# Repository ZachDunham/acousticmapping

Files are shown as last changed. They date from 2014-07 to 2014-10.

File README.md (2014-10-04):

acousticmapping
===============

Data vis, light painting mashup exploring room acoustics 

## Synopsis 
The goal for this project is to be able to photograph standing wave interference to create a kind of acoustical map of a room. Wave interference, simply put, is caused when two waves of the same frequency but different phase combine and result in a waveform that has an increased or decreased amplitude. 

In order to photograph these interference or standing wave patterns, I'm playing a range of sine tones but only working with one frequency at a time in order to isolate these interferences. In any listening situation there are direct and reflected sounds. As sound leaves the source it propagates outward, reflecting off of surfaces along the way, until it reaches your ears. Depending on where you are in the room, some portion of this sound also travels directly to the ear. Because of these alternate routes (reflected and direct) we end up with differences in arrival time which can also mean differences in the phase (angle) of the wave. As these in- or out-of-phase signals reach our ear, they can cancel each other out or combine to result in a larger waveform.

The hardware and software here are part of this ongoing project.  

## Liscense 
In the interest of collaboration and good will, the files herein are offered for public use. Just don't be a jerk about it and credit me if you use it commercially :)

## CONTAINED HEREIN
* Embedded systems design files: Namely .brd, .sch
* Firmware: Arduino sketches

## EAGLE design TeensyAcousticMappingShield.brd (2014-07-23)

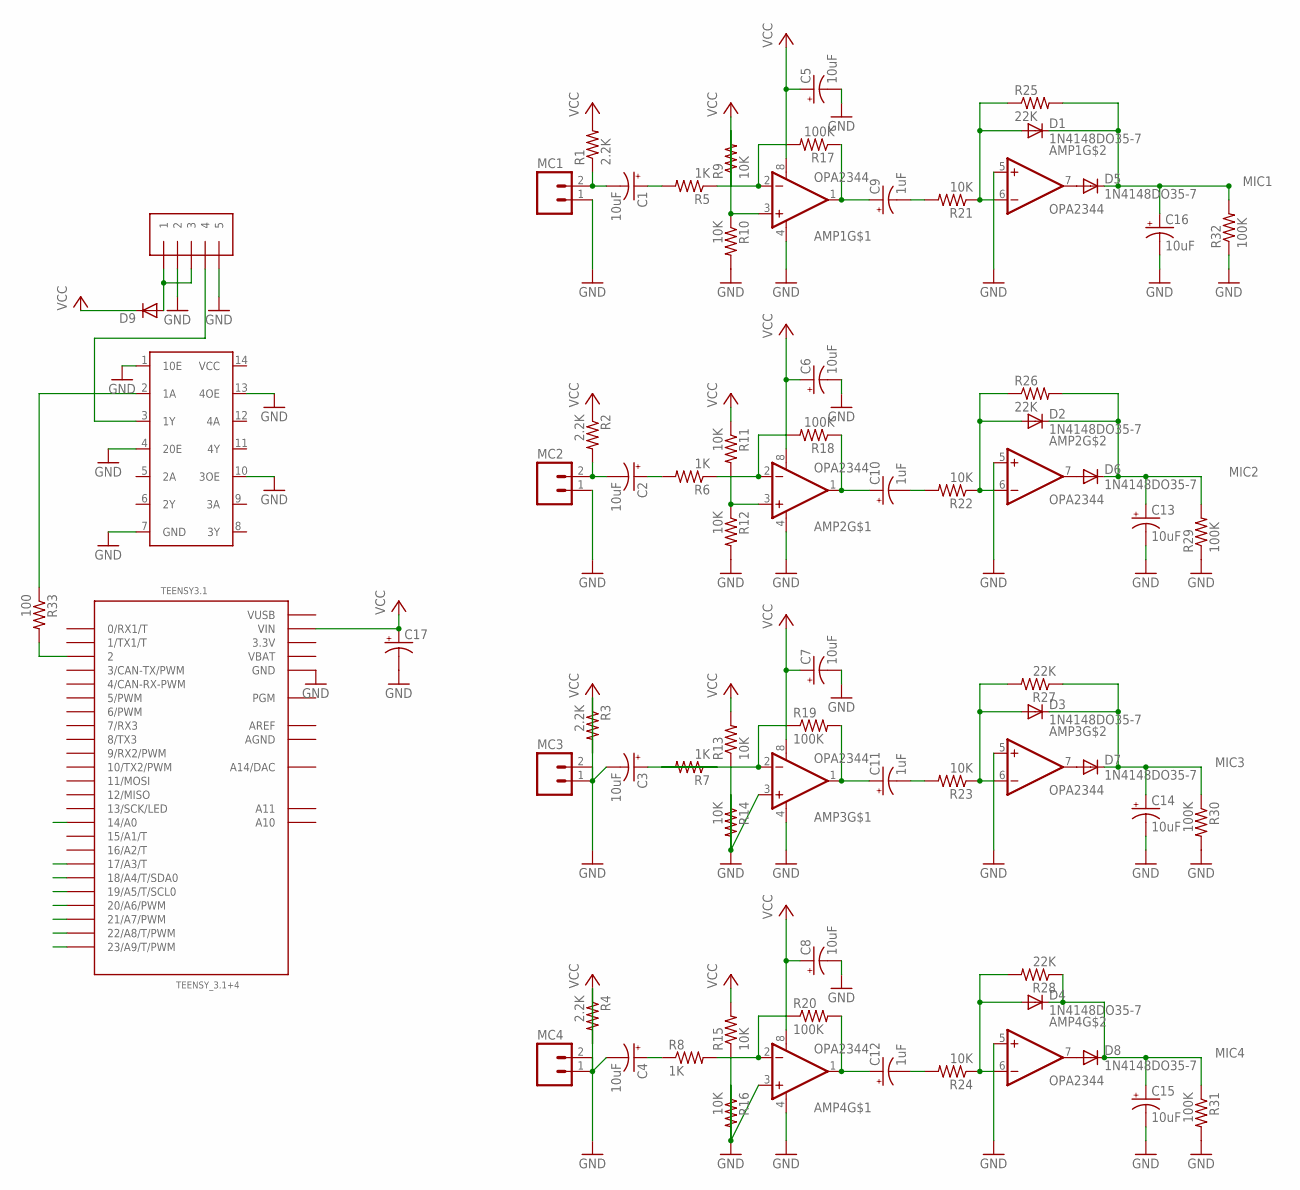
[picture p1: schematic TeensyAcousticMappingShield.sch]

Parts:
AMP1, AMP2, AMP3, AMP4: OPA2344; DIP08
C1, C2, C3, C4, C5, C6, C7, C8, C13, C14, C15, C16: 10uF; E2-4
C9, C10, C11, C12: 1uF; E2-4
C17: CPOL-USE2.5-6; E2,5-6
D1, D2, D3, D4, D5, D6, D7, D8: 1N4148DO35-7; DO35-7
D9: DIODE-C1702-05; C1702-05
IO: 1X5; 1X05-3.5MM
LEVELSHIFT: 74AHCT125; DIL14
MC1, MC2, MC3, MC4: M02LOCK_LONGPADS; 1X02_LOCK_LONGPADS
R1, R2, R3, R4: 2.2K; 0207/2V
R5, R6, R7, R8: 1K; 0207/2V
R9, R10, R11, R12, R13, R14, R15, R16, R21, R22, R23, R24: 10K; 0207/2V
R17, R18, R19, R20, R29, R30, R31, R32: 100K; 0207/2V
R25, R26, R27, R28: 22K; 0207/2V
R33: 100; 0207/2V
TEENSY3.1: TEENSY_3.1+4

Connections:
3.3V: TEENSY3.1.3.3V, TEENSY3.1.3.3V1 (3.3V)
AGND: TEENSY3.1.AGND
AREF: TEENSY3.1.AREF
B+: D9.A, IO.1, IO.3
GND: AMP1.4 (V-), AMP1.5 (+IN), AMP2.4 (V-), AMP2.5 (+IN), AMP3.4 (V-), AMP3.5 (+IN), AMP4.4 (V-), AMP4.5 (+IN), C5.-, C6.-, C7.-, C8.-, C13.-, C14.-, C15.-, C16.-, C17.-, IO.2, IO.5, LEVELSHIFT.1 (10E), LEVELSHIFT.4 (20E), LEVELSHIFT.7 (GND), LEVELSHIFT.10 (3OE), LEVELSHIFT.13 (4OE), MC1.1, MC2.1, MC3.2, MC4.2, R10.2, R12.2, R14.1, R16.1, R29.1, R32.1, TEENSY3.1.GND, TEENSY3.1.GND1 (GND)
MIC1: C16.+, D1.C, D5.C, R25.2, R32.2, TEENSY3.1.14/A0
MIC2: C13.+, D2.C, D6.C, R26.2, R29.2, TEENSY3.1.17/A3 (17/A3/T)
MIC3: C14.+, D3.C, D7.C, R27.1, R30.1, TEENSY3.1.18/A4 (18/A4/T/SDA0)
MIC4: C15.+, D4.C, D8.C, R28.1, R31.1, TEENSY3.1.19/A5 (19/A5/T/SCL0)
unnamed: AMP1.3 (+IN), R9.2, R10.1
unnamed: AMP1.2 (-IN), R5.1, R17.2
unnamed: AMP1.1 (OUT), C9.+, R17.1
unnamed: C1.+, R5.2
unnamed: C1.-, MC1.2, R1.1
unnamed: C9.-, R21.2
unnamed: AMP1.6 (-IN), D1.A, R21.1, R25.1
unnamed: AMP1.7 (OUT), D5.A
unnamed: AMP2.3 (+IN), R11.2, R12.1
unnamed: AMP2.2 (-IN), R6.1, R18.2
unnamed: AMP2.1 (OUT), C10.+, R18.1
unnamed: C2.+, R6.2
unnamed: C2.-, MC2.2, R2.2
unnamed: C10.-, R22.2
unnamed: AMP2.6 (-IN), D2.A, R22.1, R26.1
unnamed: AMP2.7 (OUT), D6.A
unnamed: AMP3.3 (+IN), R13.1, R14.2
unnamed: R33.2, TEENSY3.1.2
unnamed: LEVELSHIFT.2 (1A), R33.1
unnamed: AMP3.2 (-IN), R7.2, R19.1
unnamed: AMP3.1 (OUT), C11.+, R19.2
unnamed: C3.+, R7.1
unnamed: C3.-, MC3.1, R3.1
unnamed: C11.-, R23.2
unnamed: AMP3.6 (-IN), D3.A, R23.1, R27.2
unnamed: AMP3.7 (OUT), D7.A
unnamed: AMP4.3 (+IN), R15.1, R16.2
unnamed: AMP4.2 (-IN), R8.2, R20.1
unnamed: AMP4.1 (OUT), C12.+, R20.2
unnamed: C4.+, R8.1
unnamed: C4.-, MC4.1, R4.1
unnamed: C12.-, R24.2
unnamed: AMP4.6 (-IN), D4.A, R24.1, R28.2
unnamed: AMP4.7 (OUT), D8.A
unnamed: IO.4, LEVELSHIFT.3 (1Y)
VBAT: TEENSY3.1.VBAT
VCC: AMP1.8 (V+), AMP2.8 (V+), AMP3.8 (V+), AMP4.8 (V+), C5.+, C6.+, C7.+, C8.+, C17.+, D9.C, R1.2, R2.1, R3.2, R4.2, R9.1, R11.1, R13.2, R15.2, TEENSY3.1.VIN
VUSB: TEENSY3.1.VUSB

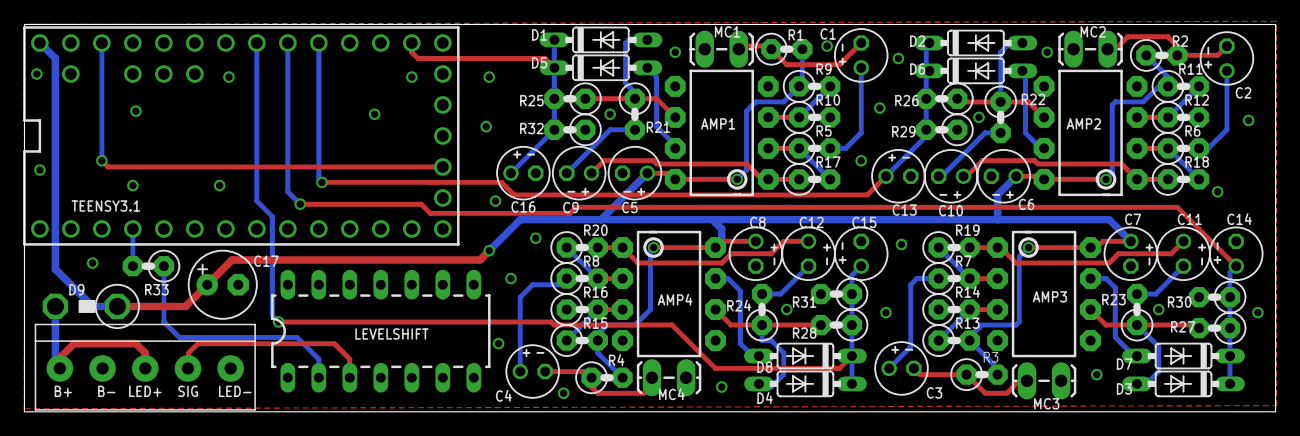
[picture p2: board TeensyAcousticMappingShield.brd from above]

Board: 2 copper layers, 102.5 x 31.8 mm, 70 parts (0 on the bottom side), 43 nets.

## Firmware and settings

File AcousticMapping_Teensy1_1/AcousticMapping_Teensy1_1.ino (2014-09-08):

#include <OctoWS2811.h>

const int ledsPerStrip = 144;

DMAMEM int displayMemory[ledsPerStrip*6];
int drawingMemory[ledsPerStrip*6];

const int config = WS2811_GRB | WS2811_800kHz;

OctoWS2811 leds(ledsPerStrip, displayMemory, drawingMemory, config);

const int num_lights = 144;
const int num_mics = 4;
const int brightness_steps = 4;

int val = 0;                     // value to store mic1
int val2 = 0;                    // value to store mic2 
int val3 = 0;                    // value to store mic 3
int val4 = 0;                    //value to store mic 4
// colors 
int r = 30;                      // red value 
int g = 0;                       // green value
int b = 30;                      // blue value

int ressteps = 1000;
const int numReadings = 20;      // number of readings for smoothing the inputs 

int readings[numReadings];       // the readings from the analog input
int total = 0;                   // the running total
int average = 0;                 // average of mic 1
int myIndex = 0;

int readings2[numReadings];      // the readings from the analog input
int total2 = 0;                  // the running total
int average2 = 0;                // average of mic 2
int myIndex2 = 0;

int readings3[numReadings];      // the readings from the analog input
int total3 = 0;                  // the running total
int average3 = 0;                // average of mic 3
int myIndex3 = 0;

int readings4[numReadings];      // the readings from the analog input
int total4 = 0;                  // the running total
int average4 = 0;                // average of mic 4
int myIndex4 = 0;

const int mic = 3;      // pin that mic1 is attached to
const int mic2 = 4;      // pin that mic2 is attached to 
const int mic3 = 5;      // pin that mic3 is attached to 
const int mic4 = 8;      // pin that mic4 is attached to 


const int ledPin = 9;           // pin that the LED is attached to
const int indicatorLedPin = 13; // pin that the built-in LED is attached to
const int buttonPin = 8;        // pin that the button is attached to


// These variables will change:
int sensorMin = 1023;  // minimum sensor value
int sensorMin2 = 1023;  // minimum sensor value2
int sensorMin3 = 1023;  // minimum sensor value3
int sensorMin4 = 1023;  // minimum sensor value4

int sensorMax = 0;     // maximum sensor value
int sensorMax2 = 0;    // maximum sensor value2
int sensorMax3 = 0;     // maximum sensor value3
int sensorMax4 = 0;     // maximum sensor value4

int sensorMaxAVG = 0;  //average max of all 4 mics 

int ledsize = (num_lights / num_mics); //size of without the * i

int x = 1.5;
/*-----------------------------------------------------------------------------------------
/////////////////////////////////////////////////////////////////////////////////////////
-----------------------------------------------------------------------------------------*/
void setup() {
  leds.begin();          // initialize pixel strip
  leds.show();           // Initialize all pixels to 'off'
  pinMode(indicatorLedPin, OUTPUT); 
  pinMode (ledPin, OUTPUT);
  pinMode (buttonPin, INPUT);
  Serial.begin(9600);

  //CALIBRATE ALL MIC'S MIN & MAX//
  
  for(int c=0; c<4000; c++){  
  calibrate_Lights(c);  
  digitalWrite(indicatorLedPin, HIGH);
    val  = running_Average(mic);     // Grab the average of Mic 1 
    val2 = running_Average2(mic2);   // Grab the average of Mic 2
    val3 = running_Average3(mic3);   // Grab the average of Mic 3
    val4 = running_Average4(mic4);   // Grab the average of Mic 4
    
    // record the maximum/minimum sensor value1
    if (val > sensorMax) {
    sensorMax = val;
    }
    if (val < sensorMin) {
    sensorMin = val;
    }
    // record the maximum/minimum sensor value2
    if (val2 > sensorMax2) {
    sensorMax2 = val2;
    }
    if (val2 < sensorMin2) {
    sensorMin2 = val2;
    }
    // record the maximum/minimum sensor value3
    if (val3 > sensorMax3) {
    sensorMax3 = val3;
    }
    if (val3 < sensorMin3) {
    sensorMin3 = val3;
    }
    // record the maximum/minimum sensor value4
    if (val4 > sensorMax4) {
    sensorMax4 = val4;
    }
    if (val4 < sensorMin4) {
    sensorMin4 = val4;
    }
  }
  sensorMaxAVG = ((sensorMin+sensorMin2+sensorMin3+sensorMin4)/4);
  digitalWrite(indicatorLedPin, LOW);

}
void loop() {
 //mic 1 
 val = running_Average(mic);  // smooth the mic readings with Running Average function
 Serial.println(val);
 val = map(val, sensorMin, sensorMaxAVG, 0, ressteps);  // map the range to res steps
 val = constrain(val, 0, ressteps);
 newledRange(val, 1); 

 //mic2
 val2 = running_Average2(mic2);  // smooth the mic readings with Running Average function
 val2 = map(val2, sensorMin2, sensorMaxAVG, 0, ressteps);  // map the range to 0-255
 val2 = constrain(val2, 0, ressteps);
 newledRange(val2, 2); 

 //mic3
 val3 = running_Average3(mic3);  // smooth the mic readings with Running Average function
 val3 = map(val3, sensorMin3, sensorMaxAVG, 0, ressteps);  // map the range to 0-255
 val3 = constrain(val3, 0, ressteps);
 newledRange(val3, 3); 

 //mic4
 val4 = running_Average4(mic4);  // smooth the mic readings with Running Average function
 val4 = map(val4, sensorMin4, sensorMaxAVG, 0, ressteps);  // map the range to 0-255
 val4 = constrain(val4, 0, ressteps);
 newledRange(val4, 4); 


leds.show();                               // refresh the strip

}

//AVERAGE MIC 1//
int running_Average(int input){  
  // subtract the last reading:
  total= total - readings[myIndex];         
  // read from the sensor:  
  readings[myIndex] = analogRead(input); 
  // add the reading to the total:
  total= total + readings[myIndex];       
  // advance to the next position in the array:  
  myIndex = myIndex + 1;                    

  // if we're at the end of the array...
  if (myIndex >= numReadings)              
    // ...wrap around to the beginning: 
    myIndex = 0;                           

  // calculate the average:
  average = total / numReadings;  
  delay(1);  
  // send it to the computer as ASCII digits
  return average;   
}
int running_Average2(int input){  
  // subtract the last reading:
  total2= total2 - readings2[myIndex2];         
  // read from the sensor:  
  readings2[myIndex2] = analogRead(input); 
  // add the reading to the total:
  total2= total2 + readings2[myIndex2];       
  // advance to the next position in the array:  
  myIndex2 = myIndex2 + 1;                    

  // if we're at the end of the array...
  if (myIndex2 >= numReadings)              
    // ...wrap around to the beginning: 
    myIndex2 = 0;                           

  // calculate the average:
  average2 = total2 / numReadings;  
  delay(1);  
  // send it to the computer as ASCII digits
  return average2;            
}
//AVERAGES MIC 3
int running_Average3(int input){  
  // subtract the last reading:
  total3= total3 - readings3[myIndex3];         
  // read from the sensor:  
  readings3[myIndex3] = analogRead(input); 
  // add the reading to the total:
  total3= total3 + readings3[myIndex3];       
  // advance to the next position in the array:  
  myIndex3 = myIndex3 + 1;                    

  // if we're at the end of the array...
  if (myIndex3 >= numReadings)              
    // ...wrap around to the beginning: 
    myIndex3 = 0;                           

  // calculate the average:
  average3 = total3 / numReadings;  
  delay(1);  
  // send it to the computer as ASCII digits
  return average3;   
}
//average mic4
int running_Average4(int input){  
  // subtract the last reading:
  total4= total4 - readings4[myIndex4];         
  // read from the sensor:  
  readings4[myIndex4] = analogRead(input); 
  // add the reading to the total:
  total4= total4 + readings4[myIndex4];       
  // advance to the next position in the array:  
  myIndex4 = myIndex4 + 1;                    

  // if we're at the end of the array...
  if (myIndex4 >= numReadings)              
    // ...wrap around to the beginning: 
    myIndex4 = 0;                           

  // calculate the average:
  average4 = total4 / numReadings;  
  delay(1);  
  // send it to the computer as ASCII digits
  return average4;   
 
}

void newledRange(int mappedval, int mic_num) {
  int rangemax = (ledsize * mic_num) -1;
  int rangemin = (ledsize * mic_num) - ledsize;
  boolean usemidpoint = false;
  int midpoint;
  int midpointlow;
  int midpointhigh;
 
  if (ledsize % 2 == 0){
    usemidpoint = true;
    midpoint = rangemin + (ledsize/2) -1; //15,45 when num_mics =
    }
  
    else{
      midpointlow = floor(ledsize/2) + rangemin - 1; 
      midpointhigh = midpointlow + 1; //ceil(ledsize/2) + rangemin - 1
       }
  
  int strength = (((mappedval * ledsize) / ressteps) / 2); // x gives a ratio of mappedval to the size of the set //MAKE SIZE OF MIDPOINT INSTEAD!!!
      turnoffleds(rangemin, rangemax);
      if ( usemidpoint == true ) {
        for(int i=midpoint; i<midpoint+strength; i++){
        leds.setPixel(i, 30, 30, 0);
        }
          for(int j=midpoint; j>midpoint-strength; --j){
            leds.setPixel(j, 30, 30, 0);
            }
      } 
       else {
         for(int i=midpoint; i<midpoint+strength; i++){
           leds.setPixel(i, 30, 30, 0);
            }
         for(int j=midpoint; j>midpoint-strength; --j){
           leds.setPixel(j, 30, 30, 0);
           }
      }
      
     
  //}
  
}

void turnoffleds(int rangemin, int rangemax) {
  for ( int i = rangemin; i <= rangemax; i++ ) {
    leds.setPixel(i, 0, 0, 0);
    } 
}

void calibrate_Lights(int c){
    c = map(c,0,4000,0,144);
    leds.setPixel(c, 0,10,30);
    leds.show();
    delayMicroseconds(1);
    leds.setPixel(c,0,0,0);
}
  

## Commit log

2014-07-23 Acoustic Mapping, Initial Commit
    Latest board and schematic files for the teensy breakout as well as the
    current teensyduino sketch I’m running (somewhat successfully).
    [TeensyAcousticMappingShield.brd, TeensyAcousticMappingShield.sch]
2014-09-08 Acoustic Mapping
    Updated code for the custom teensy breakout

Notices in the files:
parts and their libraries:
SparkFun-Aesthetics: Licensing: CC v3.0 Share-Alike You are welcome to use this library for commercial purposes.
